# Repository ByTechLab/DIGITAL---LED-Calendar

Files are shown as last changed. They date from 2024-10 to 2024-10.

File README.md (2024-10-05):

<div align="center">
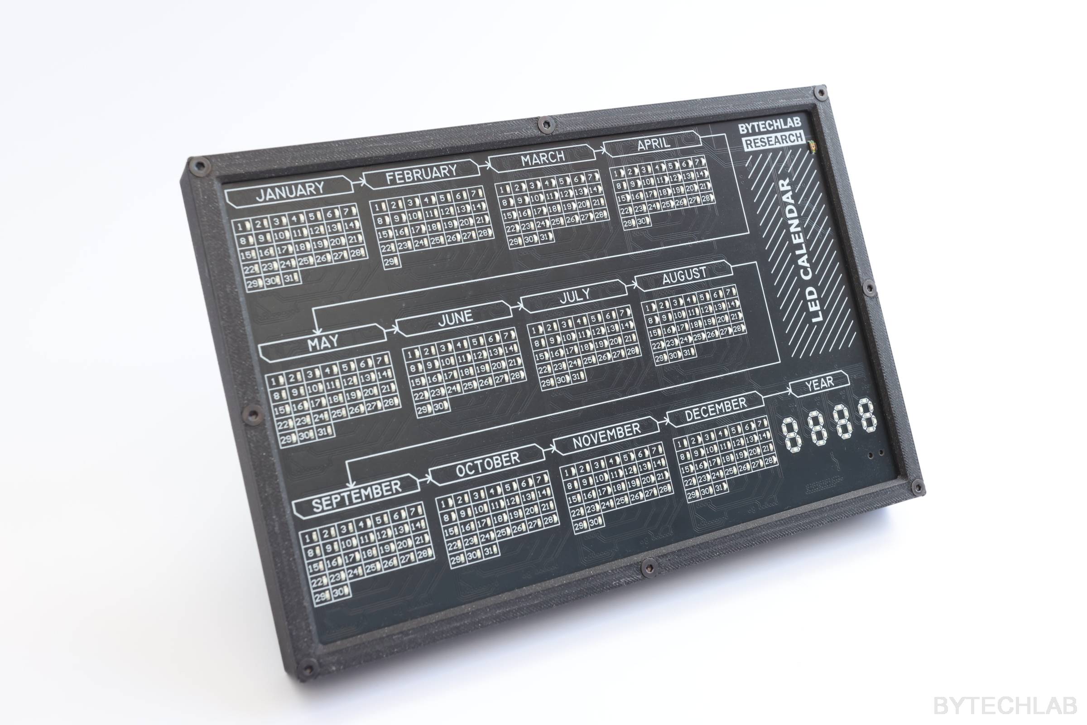
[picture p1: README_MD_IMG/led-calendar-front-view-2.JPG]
project photo
    
</div>

ESP8266 based LED calendar.

### Read more at BYTECHLAB:

<table style="width: 100%; border: none;" cellspacing="0" cellpadding="0" border="0">
  <tr>
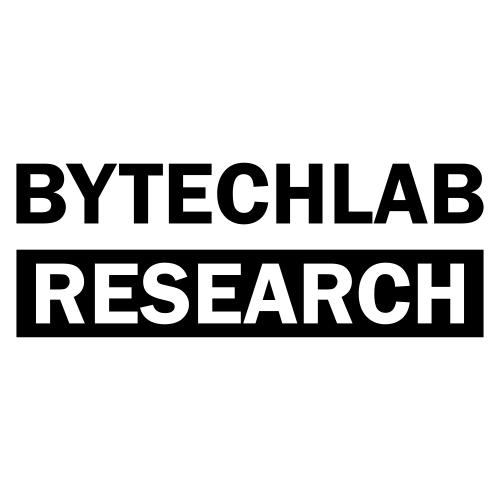
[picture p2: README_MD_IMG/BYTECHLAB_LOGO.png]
    <td></td>
    <td>https://bytechlab.com/2024/10/led-calendar-esp8266-based/</td>
  </tr>
</table>

## License
Software \ Firmware:



Hardware \ Hardware design files \ Hardware documentation:

[][cc-by-nc-sa]

[Creative Commons Attribution-NonCommercial-ShareAlike 4.0 International License][cc-by-nc-sa].

[][cc-by-nc-sa]

[cc-by-nc-sa]: http://creativecommons.org/licenses/by-nc-sa/4.0/
[cc-by-nc-sa-image]: https://licensebuttons.net/l/by-nc-sa/4.0/88x31.png
[cc-by-nc-sa-shield]: https://img.shields.io/badge/License-CC%20BY--NC--SA%204.0-lightgrey.svg

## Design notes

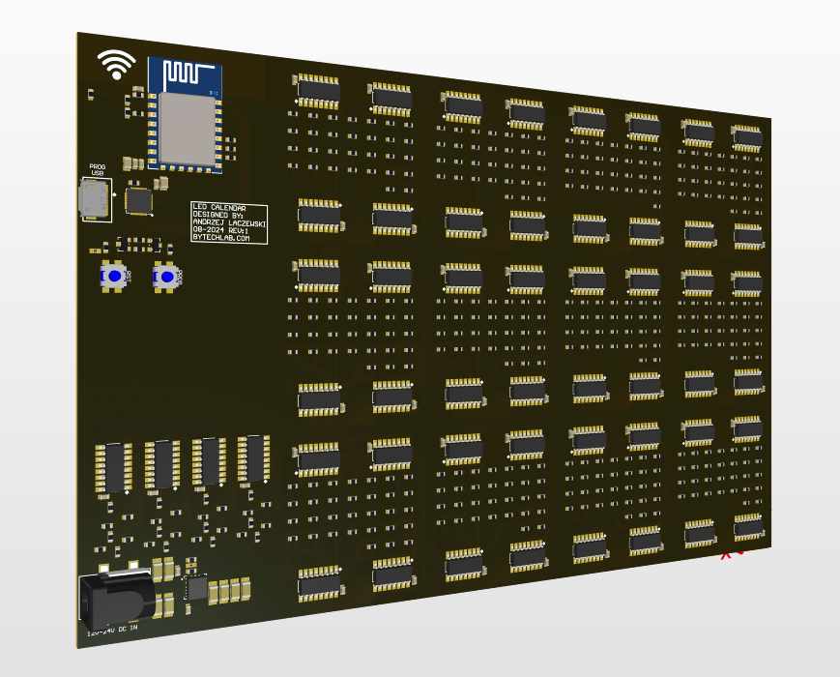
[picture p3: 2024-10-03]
PROJECT_FILES/ECAD/1_REV1/_EXPORTED_RENDERS/REAR.png

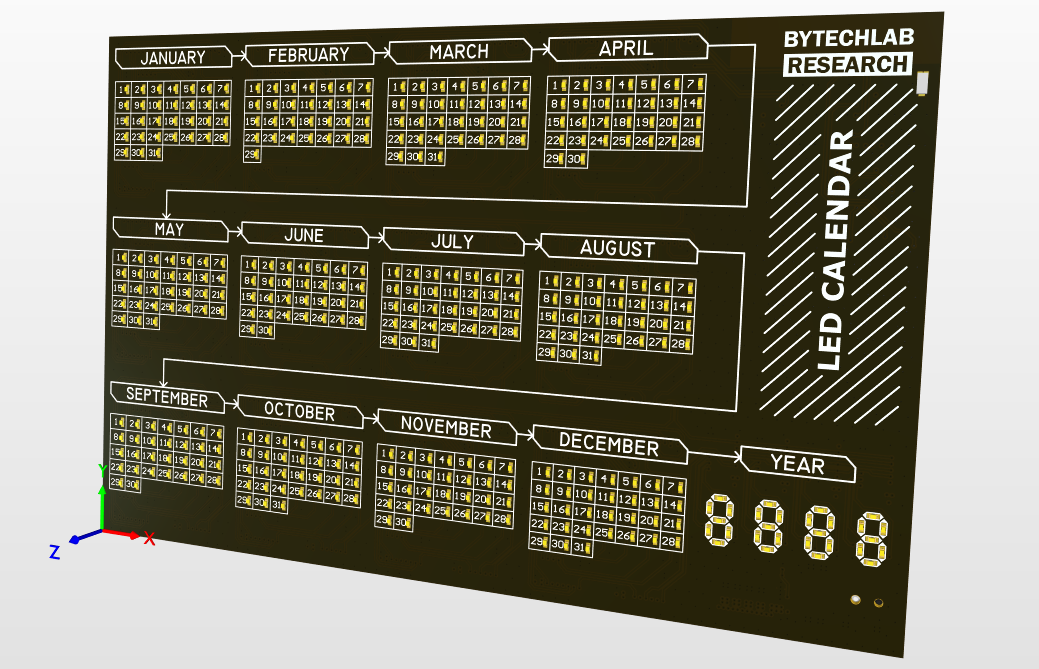
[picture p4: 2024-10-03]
PROJECT_FILES/ECAD/1_REV1/_EXPORTED_RENDERS/FRONT.png

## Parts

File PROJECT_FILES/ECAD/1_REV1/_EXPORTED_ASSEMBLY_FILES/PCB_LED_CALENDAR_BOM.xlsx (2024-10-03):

Designator | Quantity | Value | Dielectric | Voltage | Footprint | Supplier 1 | Supplier Part Number 1 | Manufacturer | Manufacturer Part Number
C1, C5 | 2 | 4.7uF | X7R | 25V | C_0805_2012 | TME |  | TDK | CGA4J1X7R1E475K125AC
C2, C3, C4, C6, C11, C13, C18, C19, C20, C21, C22, C23, C24, C25, C26, C27, C28, C29, C30, C31, C32, C33, C34, C35, C36, C37, C38, C39, C40, C41, C42, C43, C44, C45, C46, C47, C48, C49, C50, C51, C52, C53, C54, C55, C56, C57, C58, C59, C60, C61, C62, C63, C64, C65, C66, C67, C68, C69 | 58 | 100nF | X7R | 50V | C_0603_1608 | TME | CL10B104JB8NNNC | Samsung | CL10B104JB8NNNC
C7, C8, C9, C10, C14, C15 | 6 | 10uF | X5R | 50V | C_1206_3216 | TME | GRT31CR61H106KE01L | Murata | GRT31CR61H106KE01L
C12 | 1 | NC | - | 0V | C_NC_0603_1608 | TME |  | - | -
C16, C17 | 2 | 47uF | X5R | 25V | C_1206_3216 | TME | C3216X5R1E476MAC | TDK | C3216X5R1E476M160AC
D1, D2, D3, D4, D5, D6, D7, D8, D9, D10, D11, D12, D13, D14, D15, D16, D17, D18, D19, D20, D21, D22, D23, D24, D25, D26, D27, D28, D29, D30, D31, D32, D33, D34, D35, D36, D37, D38, D39, D40, D41, D42, D43, D44, D45, D46, D47, D48, D49, D50, D51, D52, D53, D54, D55, D56, D57, D58, D59, D60, D61, D62, D63, D64, D65, D66, D67, D68, D69, D70, D71, D72, D73, D74, D75, D76, D77, D78, D79, D80, D81, D82, D83, D84, D85, D86, D87, D88, D89, D90, D91, D92, D93, D94, D95, D96, D97, D98, D99, D100, D101, D102, D103, D104, D105, D106, D107, D108, D109, D110, D111, D112, D113, D114, D115, D116, D117, D118, D119, D120, D121, D122, D123, D124, D125, D126, D127, D128, D129, D130, D131, D132, D133, D134, D135, D136, D137, D138, D139, D140, D141, D142, D143, D144, D145, D146, D147, D148, D149, D150, D151, D152, D153, D154, D155, D156, D157, D158, D159, D160, D161, D162, D163, D164, D165, D166, D167, D168, D169, D170, D171, D172, D173, D174, D175, D176, D177, D178, D179, D180, D181, D182, D183, D184, D185, D186, D187, D188, D189, D190, D191, D192, D193, D194, D195, D196, D197, D198, D199, D200, D201, D202, D203, D204, D205, D206, D207, D208, D209, D210, D211, D212, D213, D214, D215, D216, D217, D218, D219, D220, D221, D222, D223, D224, D225, D226, D227, D228, D229, D230, D231, D232, D233, D234, D235, D236, D237, D238, D239, D240, D241, D242, D243, D244, D245, D246, D247, D248, D249, D250, D251, D252, D253, D254, D255, D256, D257, D258, D259, D260, D261, D262, D263, D264, D265, D266, D267, D268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 | 400 |  |  |  | LED_0603 | LCSC | C84269 | Foshan NationStar Optoelectronics | NCD0603O1
J1 | 1 | 47346-0001 |  |  | J_USB_MICROB_47346-0001 | TME |  | Molex | 47346-0001
MOD1 | 1 |  |  |  | ESP-12E | JLCPCB | C89297 | Ai-thinker | ESP-12E
P1 | 1 | DCJ250-05-A-K1-A |  |  | P_DCJ250-05-A-K1-A | TME | DCJ250-05-A-K1-A | GCT | DCJ250-05-A-K1-A
Q1, Q2 | 2 |  |  |  | SOT-23 | JLCPCB | C908252 | FUXINSEMI | S8050
QL1 | 1 |  |  |  | TEMT6000X01 | JLCPCB | C94098 | Vishay Intertech | TEMT6000X01
R1, R15 | 2 | 10k |  | 75V | R_0603_1608 | TME | CRCW060310K0FKTABC | Vishay | CRCW060310K0FKTA
R2 | 1 | 220k |  | 75V | R_0603_1608 | TME | CRCW0603220KFKTABC | Vishay | CRCW0603220KFKTABC
R3 | 1 | 100k |  | 50V | R_0603_1608 | TME | SMD0603-100K-1% | Royalohm | 0603SAF1003T5E
R4, R5, R6, R9, R11, R12, R13 | 7 | 12k |  | 50V | R_0603_1608 | TME | RC0603FR-0712K | Yageo | RC0603FR-0712KL
R7 | 1 | NC |  |  | R_NC_0603_1608 | TME |  | - | -
R8, R10 | 2 | 470R |  | 50V | R_0603_1608 | TME | RC0603FR-07470R | Yageo | RC0603FR-07470RL
R14 | 1 | 1k |  | 75V | R_0603_1608 | TME |  | Vishay | CRCW06031K00FKEA
R16 | 1 | 2.21k |  | 50V | R_0603_1608 | TME |  | Vishay | RV0603E2211BNT
R17, R18, R19, R20, R21, R22, R23, R24, R25, R26, R27, R28, R29, R30, R31, R32, R33, R34, R35, R36, R37, R38, R39, R40, R41, R42, R43, R44, R45, R46, R47, R48, R49, R50, R51, R52, R53, R54, R55, R56, R57, R58, R59, R60, R61, R62, R63, R64, R65, R66, R67, R68, R69, R70, R71, R72, R73, R74, R75, R76, R77, R78, R79, R80, R81, R82, R83, R84, R85, R86, R87, R88, R89, R90, R91, R92, R93, R94, R95, R96, R97, R98, R99, R100, R101, R102, R103, R104, R105, R106, R107, R108, R109, R110, R111, R112, R113, R114, R115, R116, R117, R118, R119, R120, R121, R122, R123, R124, R125, R126, R127, R128, R129, R130, R131, R132, R133, R134, R135, R136, R137, R138, R139, R140, R141, R142, R143, R144, R145, R146, R147, R148, R149, R150, R151, R152, R153, R154, R155, R156, R157, R158, R159, R160, R161, R162, R163, R164, R165, R166, R167, R168, R169, R170, R171, R172, R173, R174, R175, R176, R177, R178, R179, R180, R181, R182, R183, R184, R185, R186, R187, R188, R189, R190, R191, R192, R193, R194, R195, R196, R197, R198, R199, R200, R201, R202, R203, R204, R205, R206, R207, R208, R209, R210, R211, R212, R213, R214, R215, R216, R217, R218, R219, R220, R221, R222, R223, R224, R225, R226, R227, R228, R229, R230, R231, R232, R233, R234, R235, R236, R237, R238, R239, R240, R241, R242, R243, R244, R245, R246, R247, R248, R249, R250, R251, R252, R253, R254, R255, R256, R257, R258, R259, R260, R261, R262, R263, R264, R265, R266, R267, R268, R269, R270, R271, R272, R273, R274, R275, R276, R277, R278, R279, R28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 | 400 | 300R |  | 50V | R_0603_1608 | TME | RC0603FR-07300R | Yageo | RC0603FR-07300RL
S1, S2 | 2 |  |  |  | 7914G-1-000E | JLCPCB | C840653 | BOURNS | 7914G-1-000E
U1 | 1 |  |  |  | QFN28 | JLCPCB | C964632 | SKYWORKS/SILICON LABS | CP2102N-A02-GQFN28R
U2 | 1 |  |  |  | QFN9_4.5x4 |  |  | Texas Instruments | TPSM84209RKHT
U3, U4, U5, U6, U7, U8, U9, U10, U11, U12, U13, U14, U15, U16, U17, U18, U19, U20, U21, U22, U23, U24, U25, U26, U27, U28, U29, U30, U31, U32, U33, U34, U35, U36, U37, U38, U39, U40, U41, U42, U43, U44, U45, U46, U47, U48, U49, U50, U51, U52, U53, U54 | 52 |  |  |  | SO16 | Jak Electronics | 74HC595D,118 | Nexperia | 74HC595D,118

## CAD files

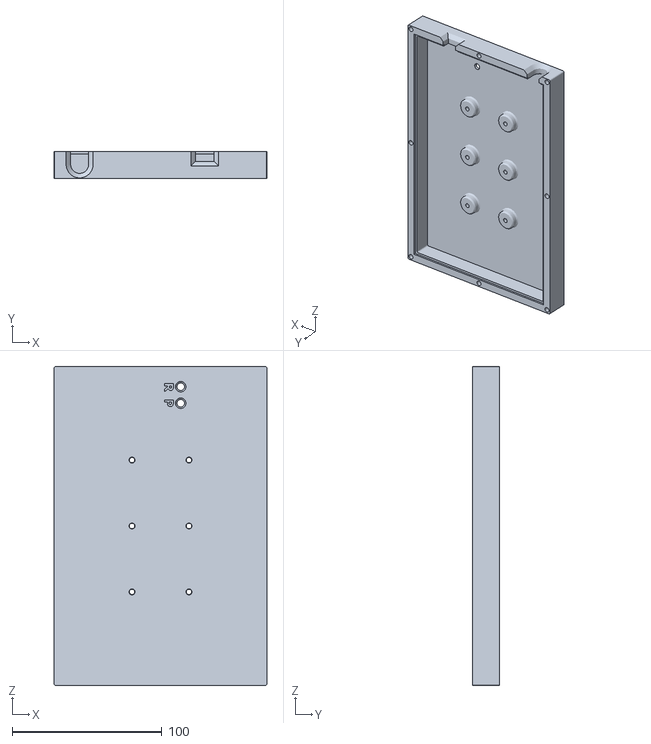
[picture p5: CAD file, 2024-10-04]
PROJECT_FILES/MCAD/2_REV2/_STL_EXPORTED/3DP_PLA_Back_Cover.stl
142.0 x 18.0 x 213.0

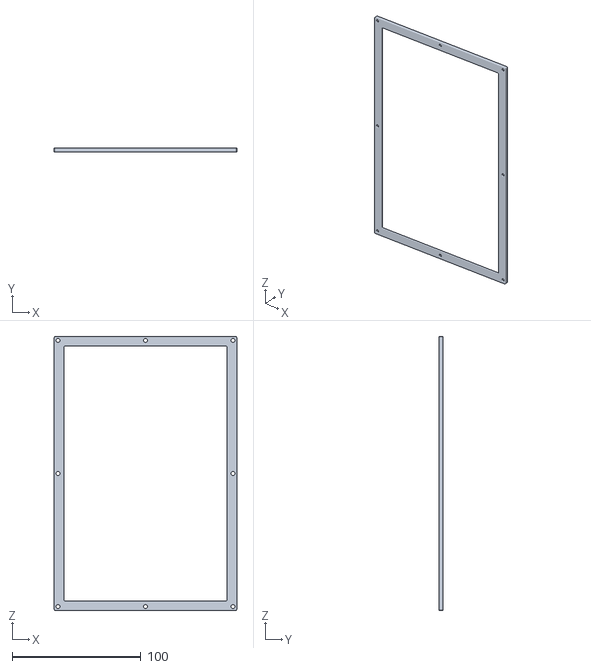
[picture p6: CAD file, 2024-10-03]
PROJECT_FILES/MCAD/2_REV2/_STL_EXPORTED/3DP_PLA_Front_Mounting_Bracket.stl
142.0 x 3.00 x 213.0

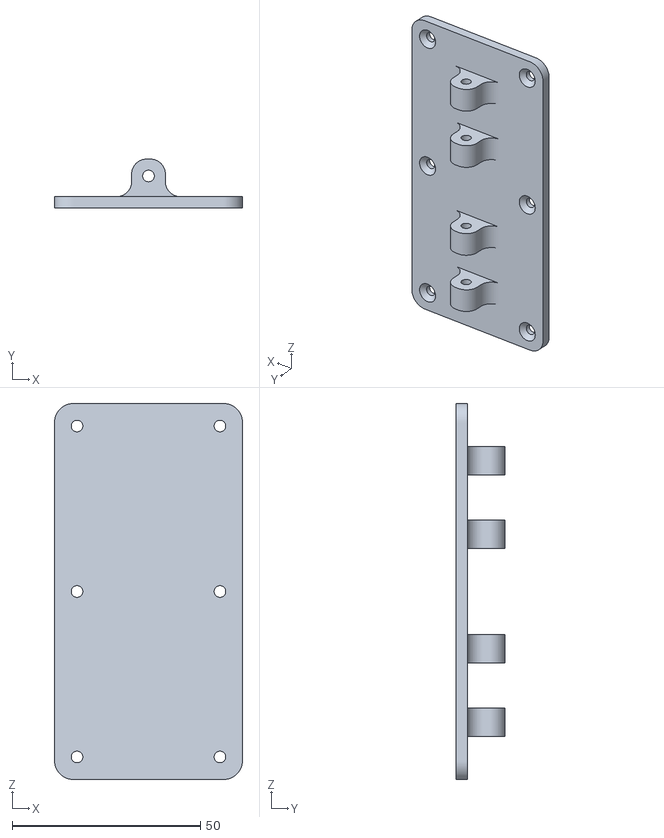
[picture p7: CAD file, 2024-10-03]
PROJECT_FILES/MCAD/2_REV2/_STL_EXPORTED/3DP_PLA_Stand_Leg_Mount.stl
50.0 x 13.0 x 100.0

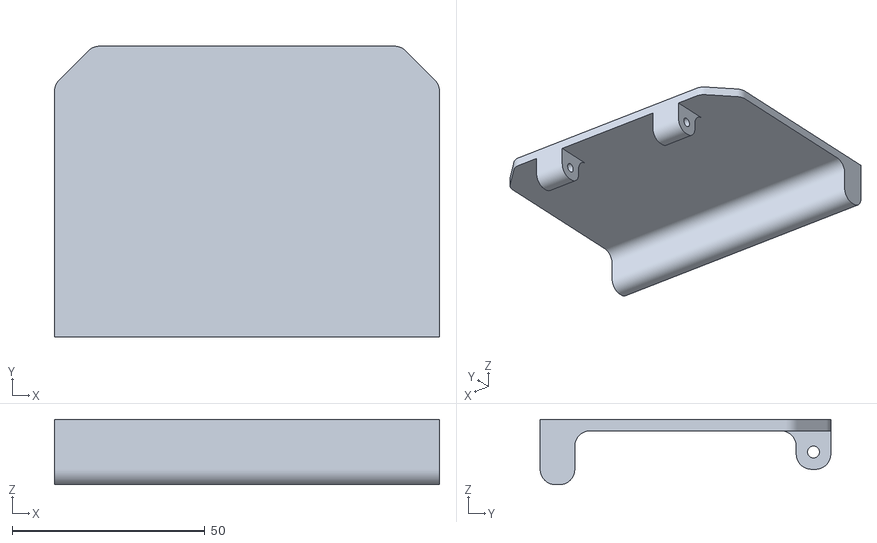
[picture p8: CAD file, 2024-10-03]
PROJECT_FILES/MCAD/2_REV2/_STL_EXPORTED/3DP_PLA_Stand_Leg.stl
100.0 x 75.5 x 17.0

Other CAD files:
PROJECT_FILES/MCAD/2_REV2/__ALTIUM_PCB_PARTS/PCB_LED_CALENDAR/PCB_LED_CALENDAR.step
PROJECT_FILES/MCAD/2_REV2/ASSEMBLY_MAIN_REVA/3DP_PLA_Back_Cover.ipt
PROJECT_FILES/MCAD/2_REV2/ASSEMBLY_MAIN_REVA/3DP_PLA_Front_Mounting_Bracket.ipt
PROJECT_FILES/MCAD/2_REV2/ASSEMBLY_MAIN_REVA/3DP_PLA_Stand_Leg.ipt
PROJECT_FILES/MCAD/2_REV2/ASSEMBLY_MAIN_REVA/3DP_PLA_Stand_Leg_Mount.ipt
PROJECT_FILES/MCAD/2_REV2/ASSEMBLY_MAIN_REVA/ASSEMBLY_Main.iam
PROJECT_FILES/MCAD/2_REV2/__ALTIUM_PCB_PARTS/PCB_LED_CALENDAR/PCB_LED_CALENDAR.iam
PROJECT_FILES/MCAD/2_REV2/__CONTENT_CENTER_PARTS/DIN 125-2 A/DIN 125-2 - A 3,2A.ipt
PROJECT_FILES/MCAD/2_REV2/__CONTENT_CENTER_PARTS/DIN 7991(2)/DIN 7991 - M3x12.ipt
PROJECT_FILES/MCAD/2_REV2/__CONTENT_CENTER_PARTS/DIN 7991(2)/DIN 7991 - M3x8.ipt
PROJECT_FILES/MCAD/2_REV2/__CONTENT_CENTER_PARTS/DIN 934/DIN 934 - M3 x 0,5.ipt
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

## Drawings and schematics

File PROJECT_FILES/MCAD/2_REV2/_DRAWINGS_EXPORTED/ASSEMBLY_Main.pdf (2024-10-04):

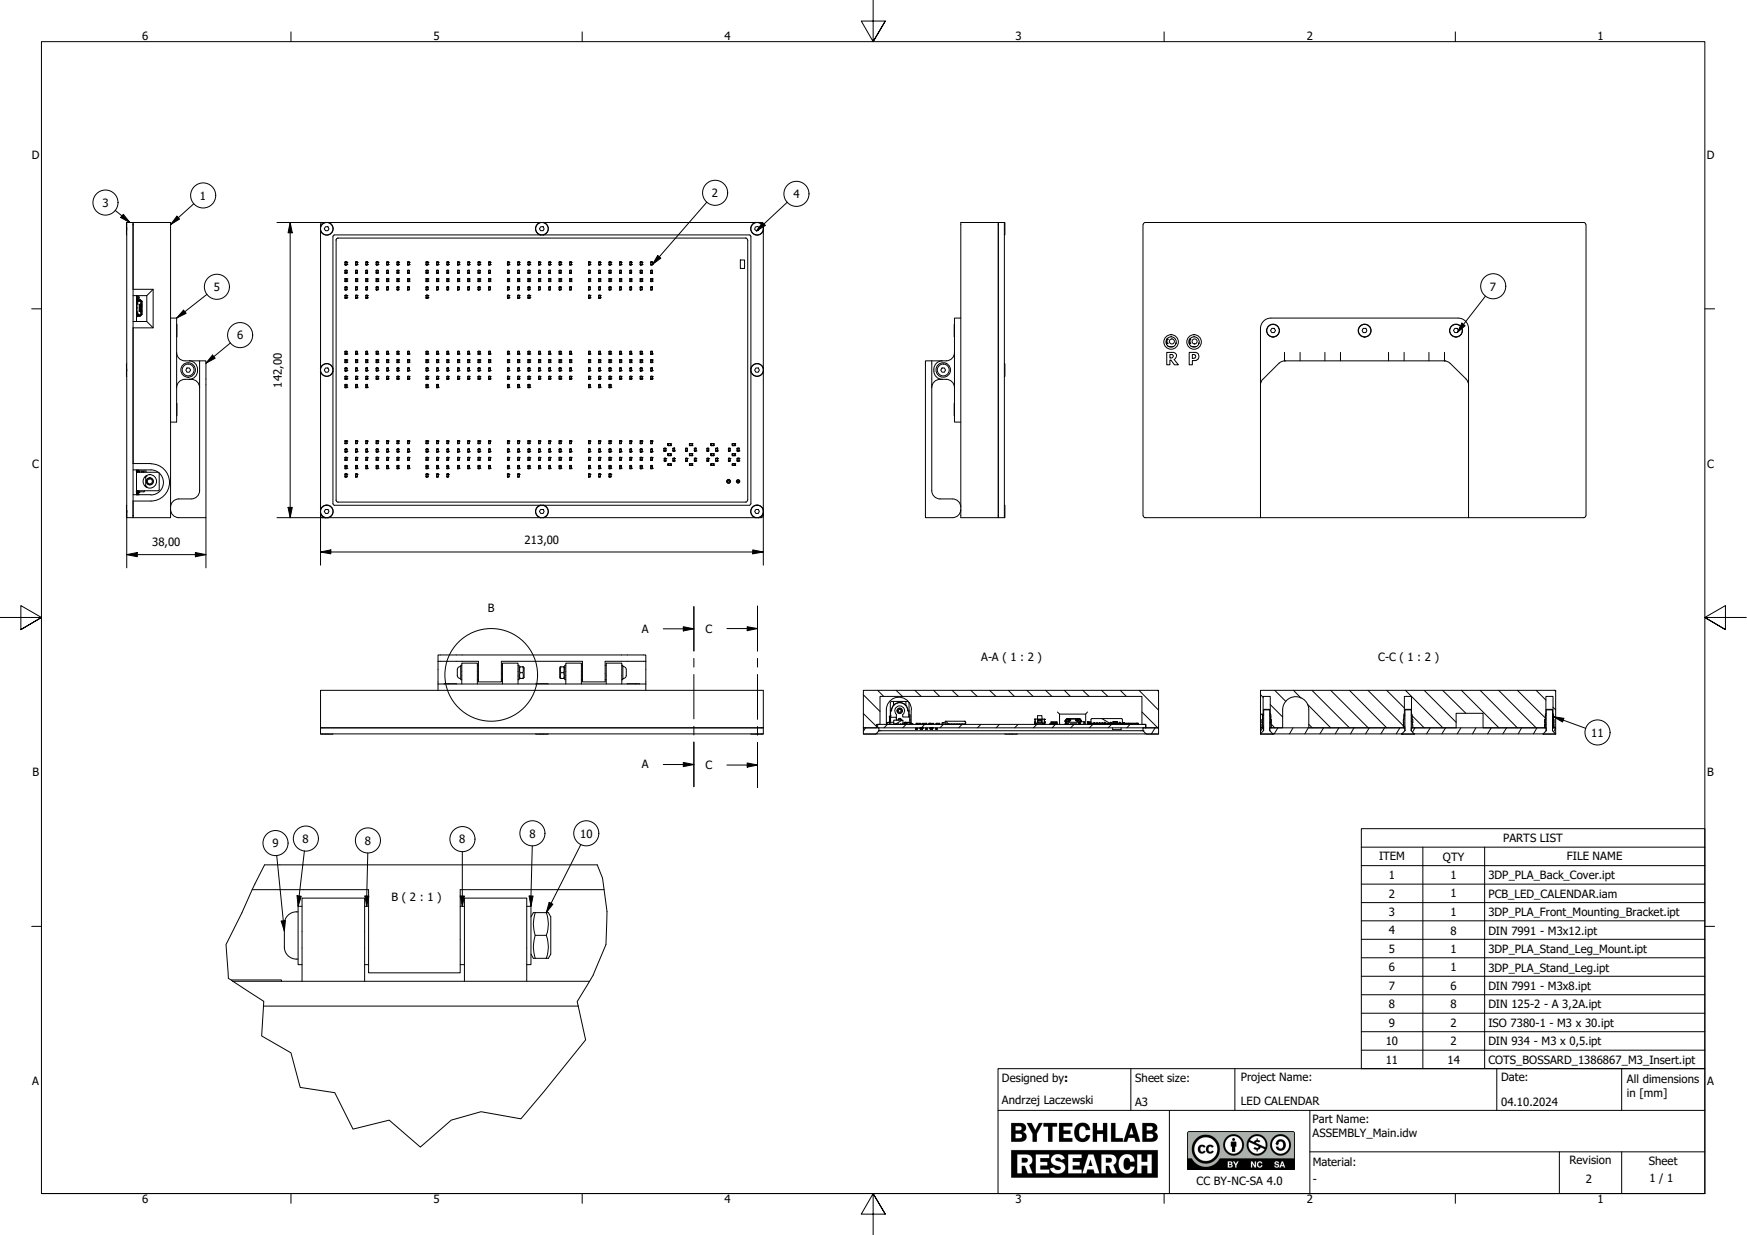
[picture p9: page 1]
PARTS LIST; ITEM; QTY; FILE NAME; DIN 7991 - M3x12.ipt; DIN 7991 - M3x8.ipt; DIN 125-2 - A 3,2A.ipt; ISO 7380-1 - M3 x 30.ipt; DIN 934 - M3 x 0,5.ipt; Andrzej Laczewski; Designed by:; Sheet size:; Date:; Part Name:; All dimensions in [mm]; Project Name:; LED CALENDAR

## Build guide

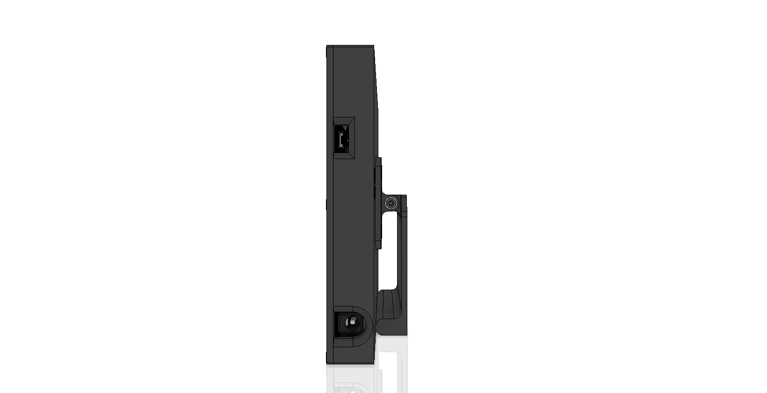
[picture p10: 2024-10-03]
PROJECT_FILES/MCAD/2_REV2/_RENDERS_EXPORTED/ASSEMBLY_Main_3.bmp

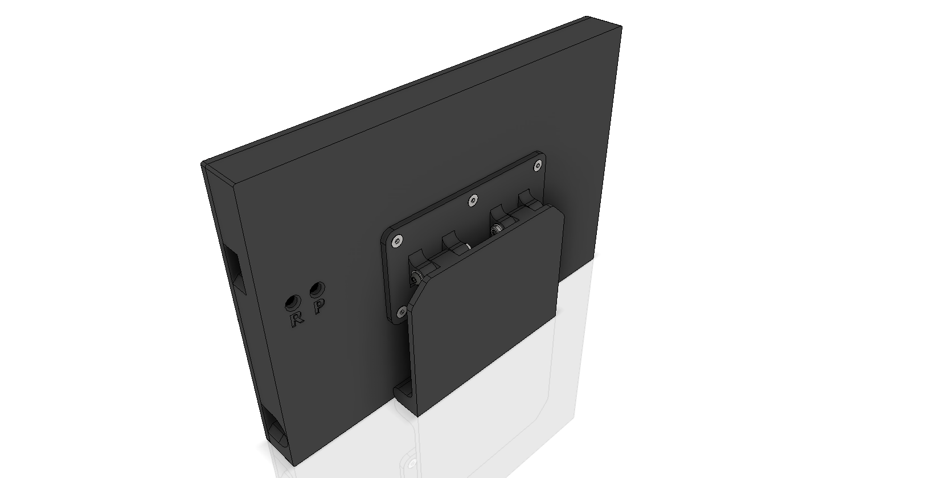
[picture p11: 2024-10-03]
PROJECT_FILES/MCAD/2_REV2/_RENDERS_EXPORTED/ASSEMBLY_Main_2.bmp

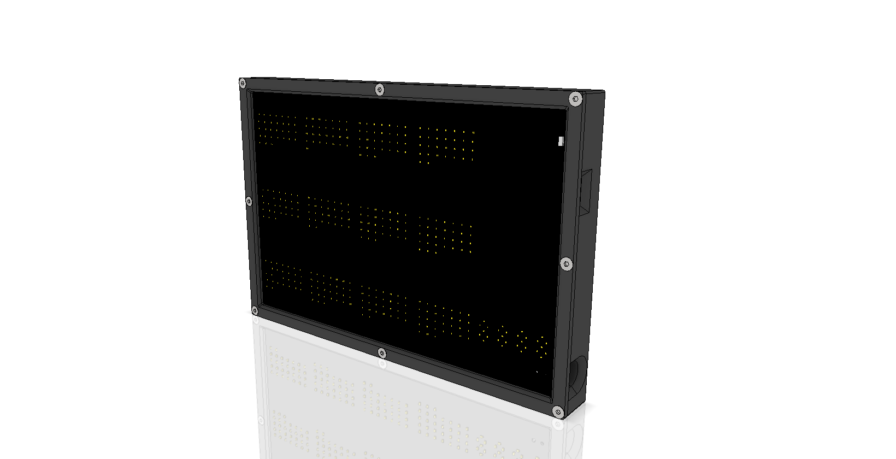
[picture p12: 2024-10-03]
PROJECT_FILES/MCAD/2_REV2/_RENDERS_EXPORTED/ASSEMBLY_Main.bmp

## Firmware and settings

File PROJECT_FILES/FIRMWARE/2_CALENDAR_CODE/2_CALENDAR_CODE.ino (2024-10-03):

#include <ESP8266WiFi.h>
#include <NTPClient.h>
#include <WiFiUdp.h>
#include <include/WiFiState.h>

// -------- TODO -------->
// * Reduce NTP request frequency - day change prediction algorithm,
// * Compile & Libraries & Upload instructions,

// ---------------- NTP ---------------->
// Replace with your network credentials
const char *ssid     = "YOUR_SSID";
const char *password = "YOUR_PASSWD";
// Set offset time in seconds to adjust for your timezone, for example:
// GMT +1 = 3600
// GMT +8 = 28800
// GMT -1 = -3600
// GMT 0 = 0
const unsigned int NTP_Timezone_Offset = 7200; //(GMT +2)

// Define NTP Client to get time
WiFiUDP ntpUDP;
NTPClient timeClient(ntpUDP, "pool.ntp.org");

unsigned int NTP_Check_Counter = 0;
#define NTP_CHECK_EVERY_N_LOOPS 30 // 60 seconds
// ---------------- NTP ----------------<

// ---------------- LED CALENDAR ---------------->
#define LED_CALENDAR_MAX_BRIGHTNESS 230
#define LED_CALENDAR_MIN_BRIGHTNESS 254

#define PIN_LED_SCK 14
#define PIN_LED_SDOUT 13
#define PIN_LED_OE 12
#define PIN_LED_STORE_DAT 5
#define PIN_LED_MASTER_RST 4

#define SHIFT_REG_SERIAL_HALF_PERIOD 25 // 25us -> 20 kHz

unsigned int LED_Calendar_Month = 1;
unsigned int LED_Calendar_Day = 1;
unsigned int LED_Calendar_Year = 0;

unsigned int LED_Calendar_Month_old = 1;
unsigned int LED_Calendar_Day_old = 1;
unsigned int LED_Calendar_Year_old = 0;

uint8_t LED_Calendar_Year_Digit_LUT [10] = 
{
    0b11111100, // 0
    0b01100000, // 1
    0b11011010, // 2
    0b11110010, // 3
    0b01100110, // 4
    0b10110110, // 5
    0b10111110, // 6
    0b11100000, // 7
    0b11111110, // 8
    0b11110110, // 9
};
// ---------------- LED CALENDAR ----------------<

void setup() 
{
  // Initialize Serial Monitor
  Serial.begin(115200);

  Serial.println("<--------- LED CALENDAR STARTUP --------->");

  LED_Calendar_Setup();
  LED_Calendar_Check_Ambient_Light();

  LED_Calendar_Clear_All_Leds();
  LED_Calendar_Startup_Animation();
  LED_Calendar_Clear_All_Leds();

  NTP_Setup();
  NTP_Update_Time_Variables();
}

void loop()
{
  if (NTP_Check_Counter >= NTP_CHECK_EVERY_N_LOOPS)
  {
    NTP_Update_Time_Variables();
    NTP_Check_Counter = 0;
  }
  else
  {
    NTP_Check_Counter++;
  }
  
  LED_Calendar_Check_Ambient_Light();

  if( LED_Calendar_Month != LED_Calendar_Month_old || LED_Calendar_Day != LED_Calendar_Day_old || LED_Calendar_Year != LED_Calendar_Year_old )
  {
    Serial.println("New date received --> Updating LEDs");
    LED_Calendar_Write_Date_To_LEDs_Animation();

    LED_Calendar_Month_old = LED_Calendar_Month;
    LED_Calendar_Day_old = LED_Calendar_Day;
    LED_Calendar_Year_old = LED_Calendar_Year;
  }

  
  delay(1000);
  LED_Calendar_Write_Date_Blink_Last_LED(1);
  delay(1000);
  LED_Calendar_Write_Date_Blink_Last_LED(0);
}

// ******************************************************************************************
// ******************************************************************************************

void NTP_Setup (void)
{
  // Connect to Wi-Fi
  Serial.print("Connecting to ");
  Serial.println(ssid);
  WiFi.begin(ssid, password);
  while (WiFi.status() != WL_CONNECTED) 
  {
    delay(500);
    Serial.print(".");
  }
  Serial.println("");
  // Initialize a NTPClient to get time
  timeClient.begin();
  timeClient.setTimeOffset(NTP_Timezone_Offset);
}

void LED_Calendar_Setup (void)
{
  pinMode(PIN_LED_SCK, OUTPUT);
  pinMode(PIN_LED_STORE_DAT, OUTPUT);

  pinMode(PIN_LED_SDOUT, OUTPUT);
  pinMode(PIN_LED_OE, OUTPUT);
  pinMode(PIN_LED_MASTER_RST, OUTPUT);

  //--------------------------------

  digitalWrite(PIN_LED_MASTER_RST, HIGH);

  analogWriteFreq(20000); // 20 kHz
  analogWrite(PIN_LED_OE, 254); // init PWM to lowest brightness
}


void NTP_Update_Time_Variables(void)
{
  timeClient.update();

  time_t epochTime = timeClient.getEpochTime();
  Serial.print("Epoch Time: ");
  Serial.print(epochTime);

  int currentHour = timeClient.getHours();
  Serial.print(",Hour: ");
  Serial.print(currentHour);  

  int currentMinute = timeClient.getMinutes();
  Serial.print(",Minutes: ");
  Serial.print(currentMinute); 
   
  int currentSecond = timeClient.getSeconds();
  Serial.print(",Seconds: ");
  Serial.print(currentSecond); 

  //Get a time structure
  struct tm *ptm = gmtime ((time_t *)&epochTime); 

  LED_Calendar_Day = ptm->tm_mday;
  Serial.print(",Month day: ");
  Serial.print(LED_Calendar_Day);

  LED_Calendar_Month = ptm->tm_mon+1;
  Serial.print(",Month: ");
  Serial.print(LED_Calendar_Month);

  LED_Calendar_Year = ptm->tm_year+1900;
  Serial.print(",Year: ");
  Serial.println(LED_Calendar_Year);
}

void LED_Calendar_Write_Date_To_LEDs_Animation (void)
{
  unsigned int number_of_day_led_target = (((LED_Calendar_Month-1)*32)+LED_Calendar_Day);

  unsigned int calendar_year_digits [4] = 
  {
    (LED_Calendar_Year % 10),
    (LED_Calendar_Year / 10) % 10,
    (LED_Calendar_Year / 100) % 10,
    (LED_Calendar_Year / 1000) % 10
  };

  for (unsigned int number_of_day_led = 0; number_of_day_led <= number_of_day_led_target; number_of_day_led++ )
  {
    for (unsigned int ii = 0 ; ii < 4 ; ii++)
    {
      uint8_t single_digit_bits = LED_Calendar_Year_Digit_LUT [calendar_year_digits[ii]];
      for (unsigned int i = 0 ; i < 8 ; i++)
      {
        
        if ((single_digit_bits & 0b00000001) == 0b00000001)
        {
          digitalWrite(PIN_LED_SDOUT, HIGH);
        }
        else
        {
          digitalWrite(PIN_LED_SDOUT, LOW);
        }
        digitalWrite(PIN_LED_SCK, LOW);
        yield();
        delayMicroseconds(SHIFT_REG_SERIAL_HALF_PERIOD);  
        digitalWrite(PIN_LED_SCK, HIGH);
        yield();
        delayMicroseconds(SHIFT_REG_SERIAL_HALF_PERIOD); 
        single_digit_bits = single_digit_bits >> 1;
      }
    }

    // Fill days with 0's
    digitalWrite(PIN_LED_SDOUT, LOW);
    for (unsigned int i = 0 ; i < (384-number_of_day_led) ; i++)
    {
      digitalWrite(PIN_LED_SCK, LOW);
      yield();
      delayMicroseconds(SHIFT_REG_SERIAL_HALF_PERIOD);  
      digitalWrite(PIN_LED_SCK, HIGH);
      yield();
      delayMicroseconds(SHIFT_REG_SERIAL_HALF_PERIOD); 
    }

    // Fill days with 1's
    digitalWrite(PIN_LED_SDOUT, HIGH);
    for (unsigned int i = 0 ; i < number_of_day_led ; i++)
    {
      digitalWrite(PIN_LED_SCK, LOW);
      yield();
      delayMicroseconds(SHIFT_REG_SERIAL_HALF_PERIOD);  
      digitalWrite(PIN_LED_SCK, HIGH);
      yield();
      delayMicroseconds(SHIFT_REG_SERIAL_HALF_PERIOD);  
    }

    digitalWrite(PIN_LED_SDOUT, LOW);

    // Latch data
    yield();
    delayMicroseconds(SHIFT_REG_SERIAL_HALF_PERIOD);                      
    digitalWrite(PIN_LED_STORE_DAT, LOW); 
    yield();
    delayMicroseconds(SHIFT_REG_SERIAL_HALF_PERIOD); 
    digitalWrite(PIN_LED_STORE_DAT, HIGH);
  }
}

void LED_Calendar_Write_Date_Blink_Last_LED (unsigned int last_led_onoff)
{
  unsigned int number_of_day_led = (((LED_Calendar_Month-1)*32)+LED_Calendar_Day) - last_led_onoff;

  unsigned int calendar_year_digits [4] = 
  {
    (LED_Calendar_Year % 10),
    (LED_Calendar_Year / 10) % 10,
    (LED_Calendar_Year / 100) % 10,
    (LED_Calendar_Year / 1000) % 10
  };

  for (unsigned int ii = 0 ; ii < 4 ; ii++)
  {
    uint8_t single_digit_bits = LED_Calendar_Year_Digit_LUT [calendar_year_digits[ii]];
    for (unsigned int i = 0 ; i < 8 ; i++)
    {
      
      if ((single_digit_bits & 0b00000001) == 0b00000001)
      {
        digitalWrite(PIN_LED_SDOUT, HIGH);
      }
      else
      {
        digitalWrite(PIN_LED_SDOUT, LOW);
      }
      digitalWrite(PIN_LED_SCK, LOW);
      yield();
      delayMicroseconds(SHIFT_REG_SERIAL_HALF_PERIOD);  
      digitalWrite(PIN_LED_SCK, HIGH);
      yield();
      delayMicroseconds(SHIFT_REG_SERIAL_HALF_PERIOD); 
      single_digit_bits = single_digit_bits >> 1;
    }
  }

  // Fill days with 0's
  digitalWrite(PIN_LED_SDOUT, LOW);
  for (unsigned int i = 0 ; i < (384-number_of_day_led) ; i++)
  {
    digitalWrite(PIN_LED_SCK, LOW);
    yield();
    delayMicroseconds(SHIFT_REG_SERIAL_HALF_PERIOD);  
    digitalWrite(PIN_LED_SCK, HIGH);
    yield();
    delayMicroseconds(SHIFT_REG_SERIAL_HALF_PERIOD); 
  }

  // Fill days with 1's
  digitalWrite(PIN_LED_SDOUT, HIGH);
  for (unsigned int i = 0 ; i < number_of_day_led ; i++)
  {
    digitalWrite(PIN_LED_SCK, LOW);
    yield();
    delayMicroseconds(SHIFT_REG_SERIAL_HALF_PERIOD);  
    digitalWrite(PIN_LED_SCK, HIGH);
    yield();
    delayMicroseconds(SHIFT_REG_SERIAL_HALF_PERIOD);  
  }

  digitalWrite(PIN_LED_SDOUT, LOW);

  // Latch data
  yield();
  delayMicroseconds(SHIFT_REG_SERIAL_HALF_PERIOD);                      
  digitalWrite(PIN_LED_STORE_DAT, LOW); 
  yield();
  delayMicroseconds(SHIFT_REG_SERIAL_HALF_PERIOD); 
  digitalWrite(PIN_LED_STORE_DAT, HIGH);
  
}

void LED_Calendar_Check_Ambient_Light (void)
{
  unsigned int ambient_light_intensity = analogRead(A0);
  analogWrite(PIN_LED_OE, map(ambient_light_intensity,0,600,LED_CALENDAR_MIN_BRIGHTNESS,LED_CALENDAR_MAX_BRIGHTNESS));
  Serial.print("Ambient Light Intensity = ");
  Serial.println(ambient_light_intensity);
}

void LED_Calendar_Startup_Animation (void)
{
  for ( unsigned int num_of_on_leds = 0 ; num_of_on_leds < 416 ; num_of_on_leds++)
  {
    // Fill days with 0's
    digitalWrite(PIN_LED_SDOUT, LOW);
    for (unsigned int i = 0 ; i < (416-num_of_on_leds) ; i++)
    {
      digitalWrite(PIN_LED_SCK, LOW);
      yield();
      delayMicroseconds(SHIFT_REG_SERIAL_HALF_PERIOD);  
      digitalWrite(PIN_LED_SCK, HIGH);
      yield();
      delayMicroseconds(SHIFT_REG_SERIAL_HALF_PERIOD);  
    }

    // Fill days with 1's
    digitalWrite(PIN_LED_SDOUT, HIGH);
    for (unsigned int i = 0 ; i < num_of_on_leds ; i++)
    {
      digitalWrite(PIN_LED_SCK, LOW);
      yield();
      delayMicroseconds(SHIFT_REG_SERIAL_HALF_PERIOD);  
      digitalWrite(PIN_LED_SCK, HIGH);
      yield();
      delayMicroseconds(SHIFT_REG_SERIAL_HALF_PERIOD);  
    }

    digitalWrite(PIN_LED_SDOUT, LOW);

    // Latch data
    yield();
    delayMicroseconds(SHIFT_REG_SERIAL_HALF_PERIOD);                     
    digitalWrite(PIN_LED_STORE_DAT, LOW); 
    yield();
    delayMicroseconds(SHIFT_REG_SERIAL_HALF_PERIOD);                     
    digitalWrite(PIN_LED_STORE_DAT, HIGH); 
  }
}

void LED_Calendar_Clear_All_Leds (void)
{
  // Fill days with 0's
  digitalWrite(PIN_LED_SDOUT, LOW);
  for (unsigned int i = 0 ; i < 416 ; i++)
  {
    digitalWrite(PIN_LED_SCK, LOW);
    yield();
    delayMicroseconds(SHIFT_REG_SERIAL_HALF_PERIOD);  
    digitalWrite(PIN_LED_SCK, HIGH);
    yield();
    delayMicroseconds(SHIFT_REG_SERIAL_HALF_PERIOD);  
  }

  digitalWrite(PIN_LED_SDOUT, LOW);

  // Latch data
  yield();
  delayMicroseconds(SHIFT_REG_SERIAL_HALF_PERIOD);                     
  digitalWrite(PIN_LED_STORE_DAT, LOW); 
  yield();
  delayMicroseconds(SHIFT_REG_SERIAL_HALF_PERIOD);                     
  digitalWrite(PIN_LED_STORE_DAT, HIGH); 
  
}

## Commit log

2024-10-03 Upload project files
    [3DP_PLA_Back_Cover.ipt, 3DP_PLA_Back_Cover.stl, 3DP_PLA_Front_Mounting_Bracket.ipt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]
2024-10-04 Upload MCAD REV2 - Inserts mod
    [3DP_PLA_Back_Cover.ipt, 3DP_PLA_Back_Cover.stl, 3DP_PLA_Front_Mounting_Bracket.ipt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]
